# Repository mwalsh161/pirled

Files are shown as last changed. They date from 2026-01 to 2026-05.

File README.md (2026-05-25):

# PIR LED Controllers

Design goals:
1. A single ESP8266 governs up to 4 LEDs + 4 PIR sensors (+4 virtual signals).
2. Any LED can trigger on/off with any grouping of PIR sensors/virtual signals.
    - Note, logical OR with each other hard-coded.
    - Each LED can have a delay associated with certain triggerers.
3. Discoverable through MDNS.
    - Service name begins with "pirled-controller"
    - Signed firmeware uploadable by Arduino OTA.
4. Config is controllable in realtime, and supports fairly aggressive polling rates.
5. No network should not prohibit core detect/dimming functionality.
    - Note, plan to allow sharing sensors...obviously that isn't included here (e.g. not making )

TODO:
1. When updating something, returning the binary app state in response can drastically cut down
   on requests (requires more complex JS logic, but that's fine).
2. Layers are currently pretty heavily tied to arduino/esp. Makes unit-testing harder.
    - Goal: leverage templates + shims to make a test build possible on non-esp hosts.
3. Sharing sensors
4. Robust to network outages (e.g. rebind as part of state machine).
    - note reboot is an easy way to do this, but given some GPIO pin activity during boot this would
      be less than ideal.
    - it would require re-"beginning" all server objects including mdns and maybe arduino ota.
    - would need same logic as setup to effectively switch to the portal

Stretch TODO:
1. ESP AP mode allows multiple to link together to continue allowing sharing sensors without network
    - what is AP range?
    - would need a "house" key to validate connecting. No security + no SSL...big yikes
    - ...maybe not.

## PlatformIO cache setup

This project uses a repo-local PlatformIO core directory at `.platformio-core/` so VS Code builds and CLI builds can share the same cache and incremental build context.

If you already have PlatformIO packages installed globally in `~/.platformio`, you can optionally symlink these into `.platformio-core/` to avoid re-downloading toolchains and frameworks:

```sh
ln -s ~/.platformio/packages .platformio-core/packages
ln -s ~/.platformio/platforms .platformio-core/platforms
```

This is optional. If the symlinks are absent, PlatformIO can manage `.platformio-core/` directly.

## Docker deployment

The API server can be built as a single production image that also contains the built frontend bundle. Build from the repo root so the Docker build can access both `api/` and `frontend/`:

```sh
docker build -f api/Dockerfile -t pirled:latest .
```

Run it with a bind mount or named volume for persistent app state at `/data` and publish port `8082`:

```sh
docker run --rm \
  -p 8082:8082 \
  -v "$(pwd)/api-data:/data" \
  pirled:latest
```

Notes:
- The image builds `frontend/dist` during `docker build`; no prebuilt frontend artifact is required.
- Persistent data is intentionally excluded from the image and should be mounted at `/data` so host backup/restore jobs can access it.
- The runtime data path can be overridden with `PIRLED_DATA_DIR`; local non-Docker runs default to `api/data`.
- Existing deploys that already mount `/app/api/data` can either move that host directory to the `/data` mount or set `PIRLED_DATA_DIR=/app/api/data`.
- The frontend already uses relative asset and API paths, which keeps it compatible with subpath deployments.

For a homelab deploy repo, the expected invocation is:

```sh
git clone <this-repo>
cd pirled
docker build -f api/Dockerfile -t pirled:latest .
docker run -d \
  --name pirled \
  --restart unless-stopped \
  -p 8082:8082 \
  -v /path/to/persistent/pirled-data:/data \
  pirled:latest
```

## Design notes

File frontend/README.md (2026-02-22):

# PIR LED Controller - React Frontend

React + TypeScript + Tailwind frontend for the PIR LED controller system.

## Development

```bash
bash dev.sh
```

Starts both the API server (port 8000) and React dev server (port 5173) with hot reload.

## Tech Stack

- **React 18** - UI framework
- **TypeScript** - Type safety
- **Vite** - Fast build tool
- **Tailwind CSS** - Styling
- **Fetch API** - HTTP client

## Architecture

The app communicates with the backend API for device discovery, configuration, and config persistence. Each React component has a single responsibility:

- Device selection and polling
- LED configuration interface
- Mood config CRUD operations

See individual `.tsx` files for implementation details.

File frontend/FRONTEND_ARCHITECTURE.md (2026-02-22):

# Frontend Architecture (High-Level)

This frontend is a React + TypeScript control surface organized around two main domains:

- `logical`: labels, groups, and moods (intent model)
- `live`: real-time LED state polling + per-endpoint updates (transport model)

The top-level container is `LogicalWorkspace`, which composes these domains into one UI.

## 1) Component Layout

```mermaid
flowchart TD
  App["App.tsx"] --> LogicalWorkspace["LogicalWorkspace.tsx"]

  LogicalWorkspace --> Header["WorkspaceHeaderSection"]
  LogicalWorkspace --> Labels["LabelMatrixSection"]
  LogicalWorkspace --> Live["LiveLedControlSection"]
  LogicalWorkspace --> Groups["GroupsSection"]
  LogicalWorkspace --> Moods["MoodStudioSection"]

  Live --> Health["DeviceHealthStrip"]
  Live --> GroupedEndpoints["LogicalEndpointSections"]
  GroupedEndpoints --> EndpointControl["LedEndpointControl (per endpoint)"]
```

## 2) State and Data Boundaries

```mermaid
flowchart LR
  UI["React Components"] --> LW["useLogicalWorkspace"]
  UI --> LT["useLiveLedTransport"]

  LW --> API["api.ts"]
  LT --> API
  LT --> Poll["useStaggeredDevicePolling"]

  API --> Backend["/api server + device HTTP endpoints"]
```

## 3) Runtime Flow (Live Control)

```mermaid
sequenceDiagram
  participant User
  participant UI as LiveLedControlSection / LedEndpointControl
  participant LT as useLiveLedTransport
  participant API as api.ts
  participant Device as Device Endpoint

  User->>UI: Change brightness/timing/PIR mask
  UI->>LT: updateEndpointDraft(endpointId, patch)
  LT->>LT: Queue + debounce per device
  LT->>API: setLedConfig(deviceUri, ledIndex, diff)
  API->>Device: POST /config/led
  LT->>API: fetchDeviceSnapshot(deviceUri)
  API->>Device: GET /combined.bin + /combined.schema
  LT-->>UI: Update snapshot, draft, dirty/pending, health
```

## 4) Runtime Flow (Logical Data + Mood Apply)

```mermaid
sequenceDiagram
  participant User
  participant UI as GroupsSection / MoodStudioSection
  participant LW as useLogicalWorkspace
  participant API as api.ts
  participant Server as FastAPI /api
  participant Device as Device Endpoint

  User->>UI: Create/Delete group
  UI->>LW: createGroup/deleteGroup
  LW->>API: POST/DELETE /api/groups
  API->>Server: Persist group JSON
  Server-->>API: Group result
  API-->>LW: Parsed response
  LW-->>UI: Updated groups state

  User->>UI: Apply mood (optional group scope)
  UI->>LW: applyMood(name, groupId)
  LW->>API: POST /api/mood-configs/{name}/apply
  API->>Server: Apply orchestration by labels/group
  Server->>Device: POST /config/led (fan-out writes)
  Server-->>API: Apply report
  API-->>LW: successCount/failureCount/failures
  LW-->>UI: Status + report
```

## Notes

- `useLogicalWorkspace` is the orchestration layer for discovery, labels, groups, and moods.
- `useLiveLedTransport` is the transport/state-sync layer for low-latency LED control.
- `api.ts` is the only frontend HTTP boundary and handles payload parsing/validation.
- Browser `localStorage` is no longer used for logical groups.
- Groups are persisted server-side via `/api/groups`.
- Mood apply orchestration is server-side via `/api/mood-configs/{name}/apply`.
- Live interactive per-LED writes still go directly from frontend to device endpoints for low-latency control.

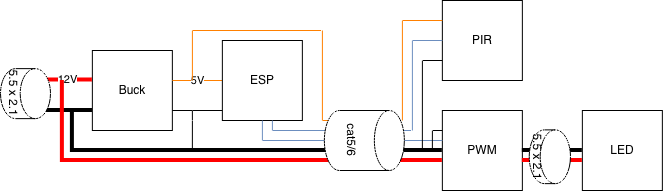
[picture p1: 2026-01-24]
block.drawio.png

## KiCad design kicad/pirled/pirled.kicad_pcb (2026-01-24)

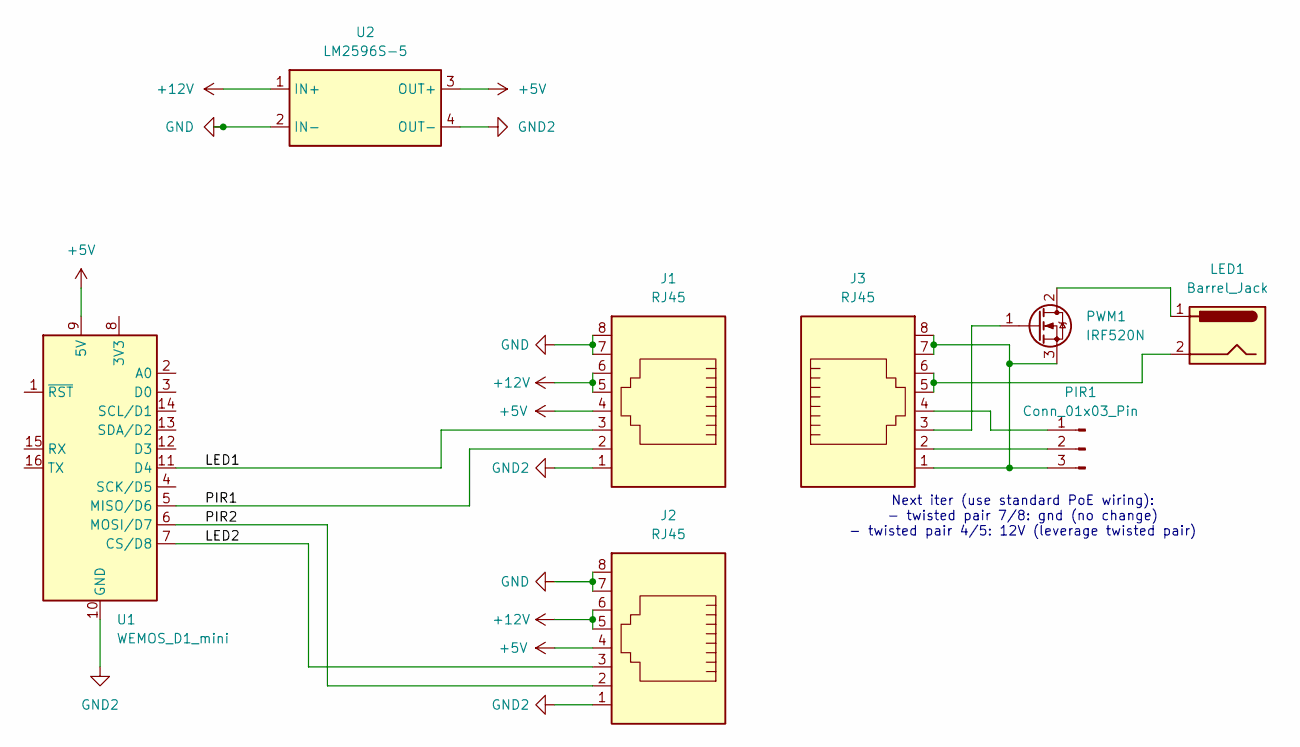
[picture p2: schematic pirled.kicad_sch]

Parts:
J1, J2, J3: RJ45; RJ45_breakout
LED1: Barrel_Jack; BarrelJack_SwitchcraftConxall_RAPC10U_Horizontal
PIR1: Conn_01x03_Pin; PinHeader_1x03_P1.00mm_Vertical
PWM1: IRF520N; TO-220-3_Vertical
U1: WEMOS_D1_mini; WEMOS_D1_mini_light
U2: LM2596S-5; Converter_DCDC_LM2596

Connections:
+5V: J1.4, J2.4, U1.9 (5V), U2.3 (OUT+)
+12V: J1.5, J1.6, J2.5, J2.6, U2.1 (IN+)
/LED1: J1.3, U1.11 (D4)
/LED2: J2.3, U1.7 (CS/D8)
/PIR1: J1.2, U1.5 (MISO/D6)
/PIR2: J2.2, U1.6 (MOSI/D7)
GND: J1.7, J1.8, J2.7, J2.8, U2.2 (IN-)
GND2: J1.1, J2.1, U1.10 (GND), U2.4 (OUT-)
unnamed: J3.5, J3.6, LED1.2
unnamed: J3.4, PIR1.1
unnamed: J3.2, PIR1.2
unnamed: J3.1, J3.7, J3.8, PIR1.3, PWM1.3 (S)
unnamed: LED1.1, PWM1.2 (D)
unnamed: J3.3, PWM1.1 (G)

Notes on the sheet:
Next iter (use standard PoE wiring): - twisted pair 7/8: gnd (no change) - twisted pair 4/5: 12V (leverage twisted pair)

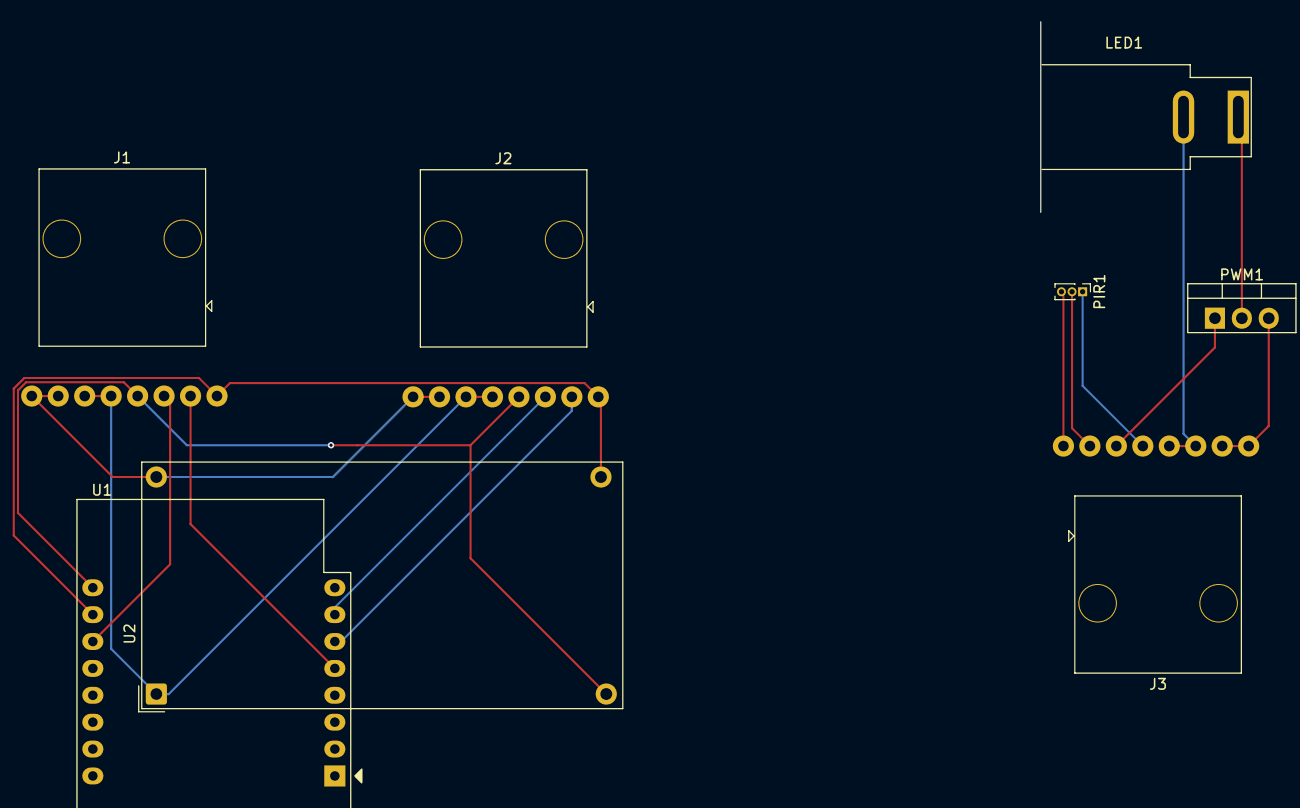
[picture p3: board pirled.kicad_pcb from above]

Board: 2 copper layers, 8 parts (0 on the bottom side), 14 nets.

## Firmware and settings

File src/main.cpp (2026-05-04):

#include "board/BoardPins.h"

#include <Arduino.h>
#include "board/RuntimeState.h"
#include "net/PortalServer.h"
#include "net/StoredWiFiCredentials.h"
#include "system/BootHistory.h"
#include "system/Logger.h"
#include "system/ResetTap.h"
#include "system/StaticNetworkConfig.h"
#include "debug.h"

namespace {
// Set when a firmware change needs setup-portal input before normal networking.
// This is intentionally tied only to network state, not versioned app config.
constexpr bool FIRMWARE_REQUIRES_STATIC_NETWORK_SETUP = true;

bool s_warningBlinkOn = false;
unsigned long s_warningBlinkLastToggle = 0;

void wipeWiFiCredentials() {
    WiFi.mode(WIFI_STA);
    WiFi.persistent(true);
    bool ok = WiFi.disconnect(true, true);  // disable STA + erase stored credentials
    WiFi.persistent(false);
    ok = clearStaticNetworkConfig() && ok;
    logAt(millis(), ok ? "dr,6" : "dr,7");  // 6=wipe ok, 7=wipe failed
    markBootHistoryWiFiWipe(ok);
}

void setupWarningBlink() {
    s_warningBlinkOn = false;
    s_warningBlinkLastToggle = 0;
    for (auto& ledController : LEDS) {
        ledController.setup();
    }
}

void updateWarningBlink() {
    unsigned long now = millis();
    if (now - s_warningBlinkLastToggle < 250) return;

    s_warningBlinkOn = !s_warningBlinkOn;
    s_warningBlinkLastToggle = now;
    for (auto& ledController : LEDS) {
        analogWrite(ledController.led().pin(), s_warningBlinkOn ? 1023 : 0);
    }
}

bool shouldRunFirmwareRequestedPortal(uint32_t resetTapCount, bool wifiCredentialsPresent,
                                      bool staticNetworkPresent) {
    if (!FIRMWARE_REQUIRES_STATIC_NETWORK_SETUP) return false;
    if (resetTapCount != 0) return false;
    if (!wifiCredentialsPresent) return false;
    return !staticNetworkPresent;
}
}  // namespace

void runPortalBlocking() {
    D_PRINTLN("Starting portal server");
    PortalServer server;
    for (int i = 0; i < 4; i++) {
        analogWrite(D4, 1023);
        delay(100);
        analogWrite(D4, 0);
        delay(100);
    }
    while (true) {
        updateResetTapWindow();
        server.handle();  // Eventually will restart ESP.
        delay(1);
    }
}

void setup() {
    D_BEGIN(115200);
    D_PRINTLN("");

    uint32_t resetTapCount = readResetTapCountForBoot();
    initBootHistory(getResetReasonCode(), resetTapCount);
    D_PRINTF("Reset reason: %lu\n", static_cast<unsigned long>(getResetReasonCode()));
    D_PRINTF("Tap candidate: %lu\n", static_cast<unsigned long>(resetTapCount));
    if (resetTapCount == RESET_TAP_WIPE_ARM) {
        D_PRINTLN("RESET_TAP_WIPE_ARM");
        analogWriteResolution(10);
        setupWarningBlink();
        resetTapCount = finalizeResetTapCountAfterWindow(updateWarningBlink);
    } else {
        resetTapCount = finalizeResetTapCountAfterWindow();
    }
    setBootHistoryTapCountFinal(resetTapCount);
    bool wifiCredentialsPresent = hasStoredWiFiCredentials();
    setBootHistoryWiFiCredentialsPresent(wifiCredentialsPresent);
    StaticNetworkConfig staticNetworkConfig{};
    bool staticNetworkPresent =
        loadStaticNetworkConfig(staticNetworkConfig) && staticNetworkConfig.enabled;
    setBootHistoryStaticNetworkPresent(staticNetworkPresent);
    bool firmwarePortalRequested =
        shouldRunFirmwareRequestedPortal(resetTapCount, wifiCredentialsPresent, staticNetworkPresent);
    setBootHistoryFirmwarePortalRequested(firmwarePortalRequested);
    D_PRINTF("Tap final: %lu\n", static_cast<unsigned long>(resetTapCount));
    if (firmwarePortalRequested) {
        D_PRINTLN("FIRMWARE_PORTAL_REQUESTED");
        runPortalBlocking();
        D_PRINTLN("Not reachable");
        ESP.restart();  // Not reachable.
    } else if (resetTapCount == RESET_TAP_PORTAL) {
        D_PRINTLN("RESET_TAP_PORTAL");
        runPortalBlocking();
        D_PRINTLN("Not reachable");
        ESP.restart();  // Not reachable.
    } else if (resetTapCount == RESET_TAP_WIPE_ARM) {
        D_PRINTLN("RESET_TAP_WIPE_ARM_EXPIRED");
    } else if (resetTapCount == RESET_TAP_WIPE) {
        D_PRINTLN("RESET_TAP_WIPE");
        wipeWiFiCredentials();
        clearResetTapState();  // prevent repeated wipe loops without additional taps
    } else {
        D_PRINTLN("NO_TAP");
    }

    analogWriteResolution(10);  // For Leds.
    CONFIG_SERVER.setup();

    WIFI_MGR.setup("pirled-");
    WIFI_MGR.subscribe([](const char* hostname) { CONFIG_SERVER.onWiFiConnected(hostname); },
                       []() { CONFIG_SERVER.onWiFiDisconnected(); });
    WIFI_MGR.subscribe([](const char* hostname) { REMOTE_PIRS.onWiFiConnected(hostname); },
                       []() { REMOTE_PIRS.onWiFiDisconnected(); });

    for (const auto& pin : PIR_PINS) {
        pinMode(pin, INPUT);
    }
    for (auto& ledController : LEDS) {
        ledController.setup();
    }
}

void loop() {
    auto now = millis();
    updateResetTapWindow();

    PirStates localPirStates = 0;
    for (size_t i = 0; i < PIR_PINS.size(); i++) {
        localPirStates |= static_cast<PirStates>(digitalRead(PIR_PINS[i]) == HIGH) << i;
    }
    REMOTE_PIRS.update(now, localPirStates);
    PIR_STATES = localPirStates | CONFIG_SERVER.pirOverrides() | REMOTE_PIRS.remotePirStates();

    for (size_t i = 0; i < LEDS.size(); i++) {
        LEDS[i].update(now, PIR_STATES);
    }

    if (WIFI_MGR.update(now)) {
        CONFIG_SERVER.handle();
    }
}

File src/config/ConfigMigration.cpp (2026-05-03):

#include "config/ConfigMigration.h"

#include <Arduino.h>
#include <EEPROM.h>
#include <ErriezCRC32.h>
#include <stddef.h>
#include <string.h>

#include "system/PersistentStorage.h"

namespace {
constexpr uint32_t CONFIG_MAGIC = 0x5049524C;  // "PIRL"
constexpr uint16_t CONFIG_VERSION_V1 = 1;
constexpr uint16_t CONFIG_VERSION_V2 = 2;
constexpr uint16_t CONFIG_VERSION_V3 = 3;
constexpr uint16_t CONFIG_VERSION_V4 = 4;
constexpr uint16_t CONFIG_VERSION_V5 = 5;
constexpr uint16_t CONFIG_VERSION_V6 = 6;
constexpr uint16_t CONFIG_VERSION_V7 = 7;

constexpr size_t LED_CONFIG_COUNT_V6 = 4;
constexpr size_t PIR_EVENT_DESTINATION_COUNT_V6 = 4;
constexpr size_t REMOTE_PIR_SLOT_COUNT_V6 = 8;
constexpr size_t REMOTE_PIR_HOST_SIZE_V6 = 32;
constexpr uint16_t REMOTE_PIR_DEFAULT_PORT_V6 = 4210;
constexpr uint32_t REMOTE_PIR_DEFAULT_LEASE_MS_V6 = 9000;
constexpr uint8_t VIRTUAL_PIR_V6 = 4;
constexpr size_t LED_CONFIG_COUNT_V7 = 4;
constexpr size_t PIR_EVENT_DESTINATION_COUNT_V7 = 4;
constexpr size_t REMOTE_PIR_SLOT_COUNT_V7 = 8;
constexpr size_t REMOTE_PIR_HOST_SIZE_V7 = 32;
constexpr uint32_t REMOTE_PIR_DEFAULT_LEASE_MS_V7 = 9000;
constexpr uint8_t VIRTUAL_PIR_V7 = 4;

struct LedConfigV1 {
    int brightness;
    uint32_t onTimeMs;
    float fadeFreq;
    uint8_t pirMask;
};

struct ConfigV1 {
    uint32_t magic;
    uint16_t version;

    char hostname[32];
    char wifiSsid[32];
    char wifiPassword[32];
    std::array<LedConfigV1, 4> ledConfig;

    uint32_t crc;
};

struct LedConfigV2 {
    int16_t brightness;
    int16_t rampOnMs;
    uint32_t holdOnMs;
    int16_t rampOffMs;
    uint8_t pirMask;
};

struct ConfigV2 {
    uint32_t magic;
    uint16_t version;

    char hostname[32];
    char wifiSsid[32];
    char wifiPassword[32];
    int64_t timestamp;
    std::array<LedConfigV2, 4> ledConfig;

    uint32_t crc;
};

struct LedConfigV3 {
    int16_t brightness;
    int16_t rampOnMs;
    uint32_t holdOnMs;
    int16_t rampOffMs;
    uint32_t waitOnMs;
    uint8_t pirMaskOn;
    uint8_t pirMaskOff;
};

struct LedConfigV3SingleMask {
    int16_t brightness;
    int16_t rampOnMs;
    uint32_t holdOnMs;
    int16_t rampOffMs;
    uint32_t waitOnMs;
    uint8_t pirMask;
};

struct SensorBindingV3 {
    uint8_t sensorId;
    uint32_t delayMs;
};

struct LedConfigV3SensorBinding {
    int16_t brightness;
    int16_t rampOnMs;
    int16_t rampOffMs;
    std::array<SensorBindingV3, 4> sensorOnBindings;
    std::array<SensorBindingV3, 4> sensorOffBindings;
    uint8_t numOnBindings;
    uint8_t numOffBindings;
};

struct ConfigV3 {
    uint32_t magic;
    uint16_t version;

    char hostname[32];
    char wifiSsid[32];
    char wifiPassword[32];
    int64_t timestamp;
    std::array<LedConfigV3, 4> ledConfig;

    uint32_t crc;
};

struct ConfigV3SingleMask {
    uint32_t magic;
    uint16_t version;

    char hostname[32];
    char wifiSsid[32];
    char wifiPassword[32];
    int64_t timestamp;
    std::array<LedConfigV3SingleMask, 4> ledConfig;

    uint32_t crc;
};

struct ConfigV3SensorBinding {
    uint32_t magic;
    uint16_t version;

    char hostname[32];
    char wifiSsid[32];
    char wifiPassword[32];
    int64_t timestamp;
    std::array<LedConfigV3SensorBinding, 4> ledConfig;

    uint32_t crc;
};

struct ConfigV4 {
    uint32_t magic;
    uint16_t version;

    int64_t timestamp;
    std::array<LedConfigV3, 4> ledConfig;

    uint32_t crc;
};

struct LedConfigV5 {
    int16_t brightness;
    int16_t rampOnMs;
    uint32_t holdOnMs;
    int16_t rampOffMs;
    uint32_t waitOnMs;
    uint16_t pirMaskOn;
    uint16_t pirMaskOff;
};

struct ConfigV5 {
    uint32_t magic;
    uint16_t version;

    int64_t timestamp;
    std::array<LedConfigV5, 4> ledConfig;

    uint32_t crc;
};

struct PirEventDestinationConfigV6 {
    char host[REMOTE_PIR_HOST_SIZE_V6];
    uint16_t port;
    bool enabled;
};

struct RemotePirConfigV6 {
    char sourceHost[REMOTE_PIR_HOST_SIZE_V6];
    uint8_t sourcePirIndex;
    uint32_t leaseMs;
    bool enabled;
};

struct ConfigV6 {
    uint32_t magic;
    uint16_t version;

    int64_t timestamp;
    std::array<LedConfigV5, LED_CONFIG_COUNT_V6> ledConfig;
    std::array<PirEventDestinationConfigV6, PIR_EVENT_DESTINATION_COUNT_V6> eventDestinations;
    std::array<RemotePirConfigV6, REMOTE_PIR_SLOT_COUNT_V6> remotePirs;

    uint32_t crc;
};

struct PirEventDestinationConfigV7 {
    char host[REMOTE_PIR_HOST_SIZE_V7];
    bool enabled;
};

struct RemotePirConfigV7 {
    char sourceHost[REMOTE_PIR_HOST_SIZE_V7];
    uint8_t sourcePirIndex;
    uint32_t leaseMs;
    bool enabled;
};

struct ConfigV7 {
    uint32_t magic;
    uint16_t version;

    int64_t timestamp;
    std::array<LedConfigV5, LED_CONFIG_COUNT_V7> ledConfig;
    std::array<PirEventDestinationConfigV7, PIR_EVENT_DESTINATION_COUNT_V7> eventDestinations;
    std::array<RemotePirConfigV7, REMOTE_PIR_SLOT_COUNT_V7> remotePirs;

    uint32_t crc;
};
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

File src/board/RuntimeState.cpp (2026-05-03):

#include "board/RuntimeState.h"
#include "board/BoardPins.h"

namespace {
Controller makeController(uint8_t index, uint8_t pin, LedConfig& ledCfg) {
    return {index,
            pin,
            ledCfg.brightness,
            ledCfg.rampOnMs,
            ledCfg.holdOnMs,
            ledCfg.rampOffMs,
            ledCfg.waitOnMs,
            ledCfg.pirMaskOn,
            ledCfg.pirMaskOff};
}
}  // namespace

std::array<Controller, 4> LEDS = {{
    makeController(0, D4, getLedConfig(0)),  // oof D4...epileptic on reset.
    makeController(1, D8, getLedConfig(1)),
    makeController(2, D5, getLedConfig(2)),
    makeController(3, D3, getLedConfig(3)),
}};
std::array<uint8_t, 4> PIR_PINS{D6, D7, D1, D2};
PirStates PIR_STATES = 0;

WiFiManager WIFI_MGR;
ConfigServer CONFIG_SERVER;
RemotePirManager REMOTE_PIRS;

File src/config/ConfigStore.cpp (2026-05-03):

#include "config/ConfigStore.h"

#include <Arduino.h>
#include <EEPROM.h>
#include <ErriezCRC32.h>
#include <stddef.h>

#include "config/ConfigMigration.h"
#include "debug.h"
#include "system/BootHistory.h"
#include "system/Logger.h"
#include "system/PersistentStorage.h"

#define VIRTUAL_PIR 4

namespace {
constexpr uint32_t CONFIG_MAGIC = 0x5049524C;  // "PIRL"
constexpr uint16_t CONFIG_VERSION = CURRENT_CONFIG_VERSION;
Config s_config;
constexpr uint8_t CFG_SAVE_NO_CHANGE = 0;
constexpr uint8_t CFG_SAVE_COMMITTED = 1;
constexpr uint8_t CFG_SAVE_COMMIT_FAILED = 2;

uint32_t computeCrc(const Config& cfg) {
    return crc32Buffer(reinterpret_cast<const uint8_t*>(&cfg), offsetof(Config, crc));
}

void setConfigDefaults() {
    memset(&s_config, 0, sizeof(s_config));

    s_config.magic = CONFIG_MAGIC;
    s_config.version = CONFIG_VERSION;

    for (size_t i = 0; i < s_config.ledConfig.size(); i++) {
        PirStates pirMask = static_cast<PirStates>((1U << i) | (1U << (i + VIRTUAL_PIR)));
        s_config.ledConfig[i] = {.brightness = 1023,
                                 .rampOnMs = 1000,
                                 .holdOnMs = 10000,
                                 .rampOffMs = 1000,
                                 .waitOnMs = 0,
                                 .pirMaskOn = pirMask,
                                 .pirMaskOff = pirMask};
    }

    for (auto& destination : s_config.eventDestinations) {
        destination.host[0] = '\0';
        destination.enabled = false;
    }

    for (auto& remotePir : s_config.remotePirs) {
        remotePir.sourceHost[0] = '\0';
        remotePir.sourcePirIndex = 0;
        remotePir.leaseMs = REMOTE_PIR_DEFAULT_LEASE_MS;
        remotePir.enabled = false;
    }

    s_config.crc = computeCrc(s_config);
}
}  // namespace

const Config& getConfig() { return s_config; }
LedConfig& getLedConfig(size_t index) { return s_config.ledConfig[index]; }
PirEventDestinationConfig& getPirEventDestinationConfig(size_t index) {
    return s_config.eventDestinations[index];
}
RemotePirConfig& getRemotePirConfig(size_t index) { return s_config.remotePirs[index]; }
void setConfigTimestamp(int64_t timestamp) { s_config.timestamp = timestamp; }

bool initConfig() {
    beginPersistentStorage();
    EEPROM.get(0, s_config);

    uint16_t storedVersion = s_config.version;
    uint32_t storedCrc = s_config.crc;
    uint32_t computedCrc = computeCrc(s_config);
    bool magicValid = s_config.magic == CONFIG_MAGIC;
    bool versionValid = s_config.version == CONFIG_VERSION;
    bool crcValid = s_config.crc == computedCrc;
    bool valid = magicValid && versionValid && crcValid;
    bool recoveredStoredConfig = valid;
    uint8_t bootSource = CFG_BOOT_SOURCE_STORED;
    bool migrationAttempted = false;
    bool migrationSucceeded = false;
    bool migrationSaveSucceeded = false;

    if (!valid) {
        if (magicValid) {
            setConfigDefaults();
        }
        migrationAttempted = magicValid;
        if (magicValid && migrateStoredConfig(storedVersion, s_config)) {
            char migrationStatus[16] = "";
            snprintf(migrationStatus, sizeof(migrationStatus), "cm,%u,%u", storedVersion, CONFIG_VERSION);
            logAt(millis(), migrationStatus);
            D_PRINTLN(migrationStatus);
            D_PRINTLN("Stored config migrated");
            bootSource = CFG_BOOT_SOURCE_MIGRATED;
            recoveredStoredConfig = true;
            migrationSucceeded = true;
            migrationSaveSucceeded = saveConfig();
        } else {
            D_PRINTLN("Stored config invalid, loading defaults");
            if (!magicValid) {
                setConfigDefaults();
            }
            bootSource = CFG_BOOT_SOURCE_DEFAULTS;
        }
    }

    setBootHistoryConfigLoad(bootSource, magicValid, versionValid, crcValid, storedVersion,
                             CONFIG_VERSION, storedCrc, computedCrc, migrationAttempted,
                             migrationSucceeded, migrationSaveSucceeded);

    // cb,<boot_source>,<valid>,<magic_ok>,<version_ok>,<crc_ok>,<stored_version>
    char bootStatus[24] = "";
    snprintf(bootStatus, sizeof(bootStatus), "cb,%u,%u,%u,%u,%u,%u", bootSource, valid,
             magicValid, versionValid, crcValid, storedVersion);
    logAt(millis(), bootStatus);
    D_PRINTLN(bootStatus);

    // cc,<stored_crc_hex>,<computed_crc_hex>
    char crcStatus[24] = "";
    snprintf(crcStatus, sizeof(crcStatus), "cc,%08lX,%08lX",
             static_cast<unsigned long>(storedCrc), static_cast<unsigned long>(computedCrc));
    logAt(millis(), crcStatus);
    D_PRINTLN(crcStatus);

    return recoveredStoredConfig;
}
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

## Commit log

2026-01-03 refactor led cntl and simplify wifi creds
2026-01-07 decouple led ctl and sense
2026-01-21 arduino OTA
2026-01-24 overhaul Led and up; patch bugs in server/client; add logger/debug tools
    [Config.cpp, Led.cpp]
2026-01-24 add kicad
    [pirled.kicad_pcb, pirled.kicad_sch]
2026-01-25 switch to binary protocol
2026-01-25 fix enum size in binary
    [WireProtocol.cpp, main.cpp]
2026-01-31 add jitter
2026-02-01 add firmware version by commit; leverage post requests to replace polling
    [AppState.cpp, Config.cpp]
2026-02-22 Convert to a react app and add persisting config framework
2026-02-22 fix unsigned error; no save debounce; use rtc mem for double and tripple tap resets; more reseed and restart in wifi state machine
    [Config.cpp, WiFiManager.h, WireProtocol.cpp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]
2026-02-23 feat(live): restore group collapse and visible-device polling
2026-02-25 feat(live-controls): handle unresolved devices and simplify LED endpoint config UI
2026-02-25 use volta instead of conda for node
2026-04-12 no reboots while retrying wifi; explicit portal mode
    [WiFiManager.h, main.cpp]
2026-05-02 Prioritize LED updates in the main loop
2026-05-02 Expose runtime LED state through read-only accessors
2026-05-02 Extract reset-tap boot handling
    [main.cpp]
2026-05-02 Rename board and runtime state headers
2026-05-02 Fix reset reason debug format
    [main.cpp]
2026-05-02 Add remote sensor sharing UI
2026-05-03 better initial load flow to use cache unless user needs to explicitly have server refresh
2026-05-03 hard-code udp port for sensor sharing
2026-05-03 refactor frontend to be more intuitive with remote sensors
2026-05-03 Simplify WiFi retry flow after DHCP testing
    Extensive testing pointed away from our application-level recovery logic and toward an ESP8266 SDK DHCP client issue. Static IP succeeded immediately, while auto-reseed, portal-style rewrites, radio resets, and explicit DHCP client restarts did not reliably recover DHCP.
    Given that result, this change removes the heavier warm/cold retry state machine and keeps only a lightweight periodic reattach loop for ordinary network hiccups. Wrong-password remains terminal until reboot, but normal disconnects now fall back to a simple reconnect attempt every 10 seconds.
    [WiFiManager.h]
2026-05-03 Require static WiFi network config on ESP8266
    Persist static IP settings outside the versioned app config and collect them through the setup portal.
    Remove the boot-time WiFi reseed path and keep reconnect behavior lightweight after testing showed the ESP8266 SDK DHCP client can associate and receive offers without completing requests.
    Add a 3-tap LED warning window so the following tap is required before wiping stored WiFi/static network settings.
2026-05-04 tighten up cors handling to one layer (and fix remote_pir cors issue)
    [ConfigServer.cpp, WireProtocol.cpp]
2026-05-25 Resolve devices by hostname when mDNS service data is missing
    Add a default device HTTP port and fall back to resolving <device>.local via getaddrinfo when cached mDNS service info is unavailable or lacks an IPv4 address.
